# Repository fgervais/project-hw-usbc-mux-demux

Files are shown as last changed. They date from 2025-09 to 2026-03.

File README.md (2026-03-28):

# USB-C mux/demux

Overview

## Use-cases

Basically used to mux or demux usb 2.0 data bus with USB-PD up to and including
revision 3.1 at 48V.

Here's an illustration highlighting a couple use-cases:

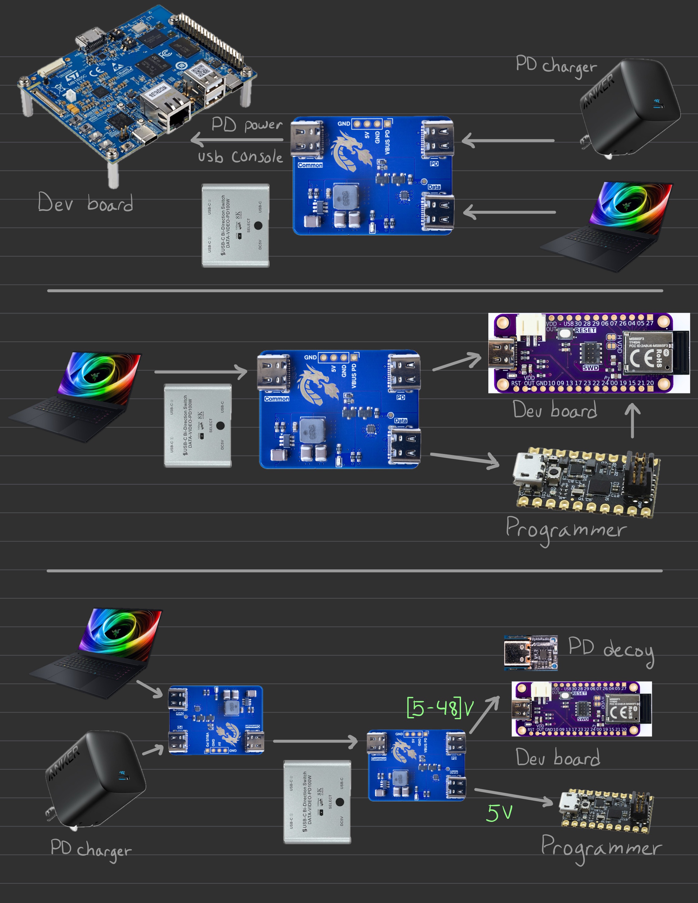
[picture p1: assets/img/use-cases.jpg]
Use-Cases


## Switching converter analysis

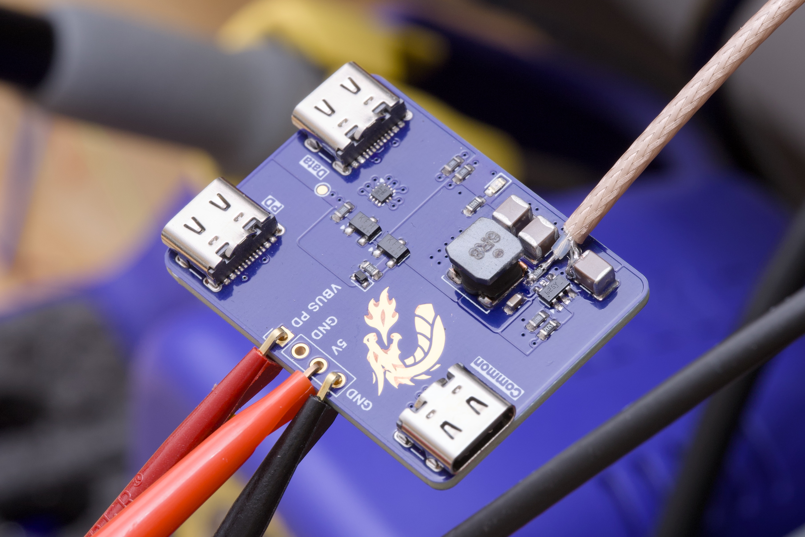
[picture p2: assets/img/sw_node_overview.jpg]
Overview


50 ohms series termination at the SW node.

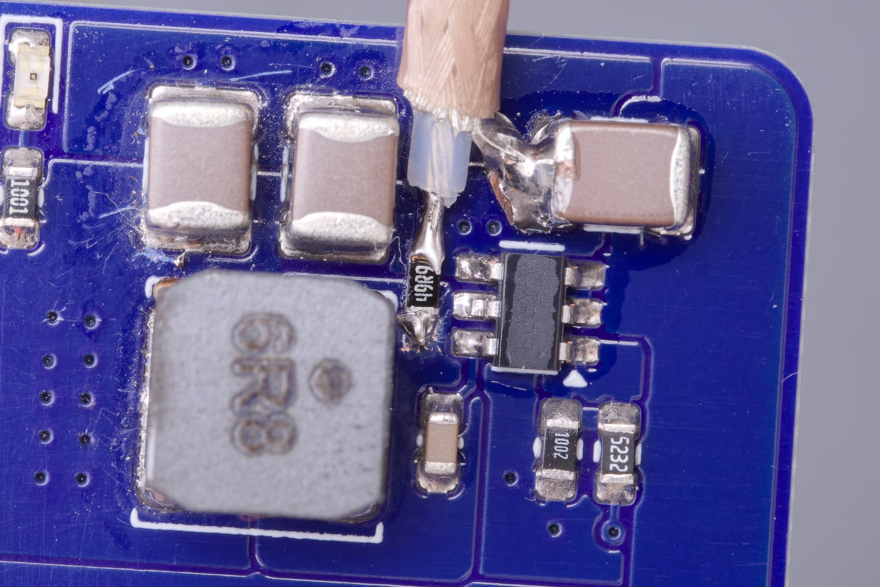
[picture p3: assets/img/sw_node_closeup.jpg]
Closeup


### Switch node

| Input Voltage | Waveform | Rising edge |
|---|---|---|
| 10V | Waveform | Rising |
| 20V | Waveform | Rising |
| 48V | Waveform | Rising |

### Output (5V)

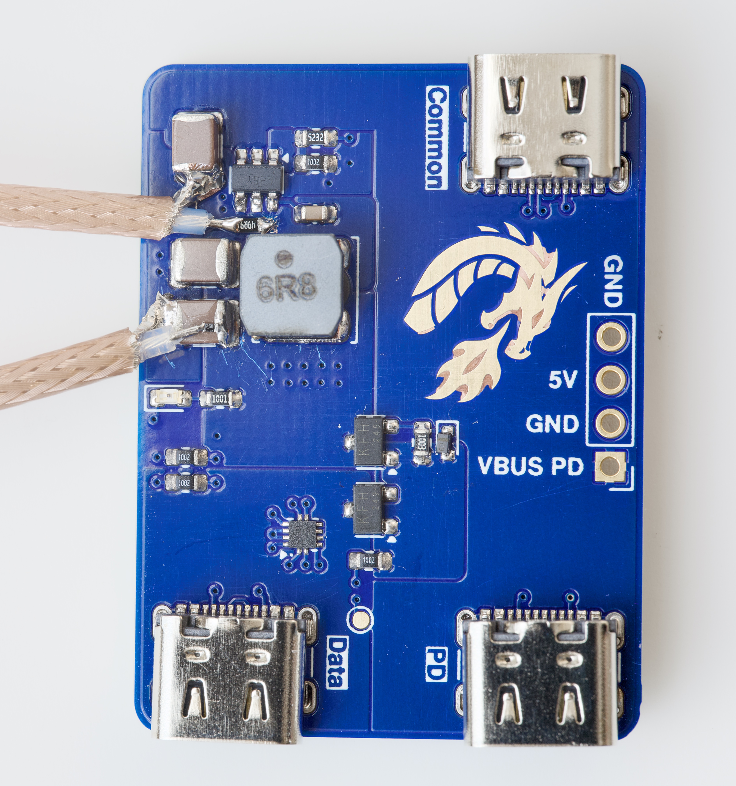
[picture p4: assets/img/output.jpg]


| Input Voltage | No Load | 50 mA | 500 mA | 1 A |
|---|---|---|---|-----|
| 10V | Waveform | Waveform | Waveform | Waveform |
| 20V | Waveform | Waveform | Waveform | Waveform |
| 48V | Waveform | Waveform | Waveform | Waveform |

| Input Voltage | No Load | 50 mA | 500 mA | 1 A |
|---|---|---|---|-----|
| 10V | Waveform | Waveform | Waveform | Waveform |
| 20V | Waveform | Waveform | Waveform | Waveform |
| 48V | Waveform | Waveform | Waveform | Waveform |

### Noise

| Input Voltage | No Load | 50 mA | 500 mA | 1 A |
|---|---|---|---|-----|
| 10V | 17.60 mV (0.35%) | 19.80 mV (0.40%) | 13.00 mV (0.26%) | 12.40 mV (0.25%) |
| 20V | 13.40 mV (0.27%) | 14.80 mV (0.30%) | 15.20 mV (0.30%) | 15.40 mV (0.31%) |
| 48V | 15.00 mV (0.30%) | 17.60 mV (0.35%) | 28.20 mV (0.56%) | 19.60 mV (0.39%) |

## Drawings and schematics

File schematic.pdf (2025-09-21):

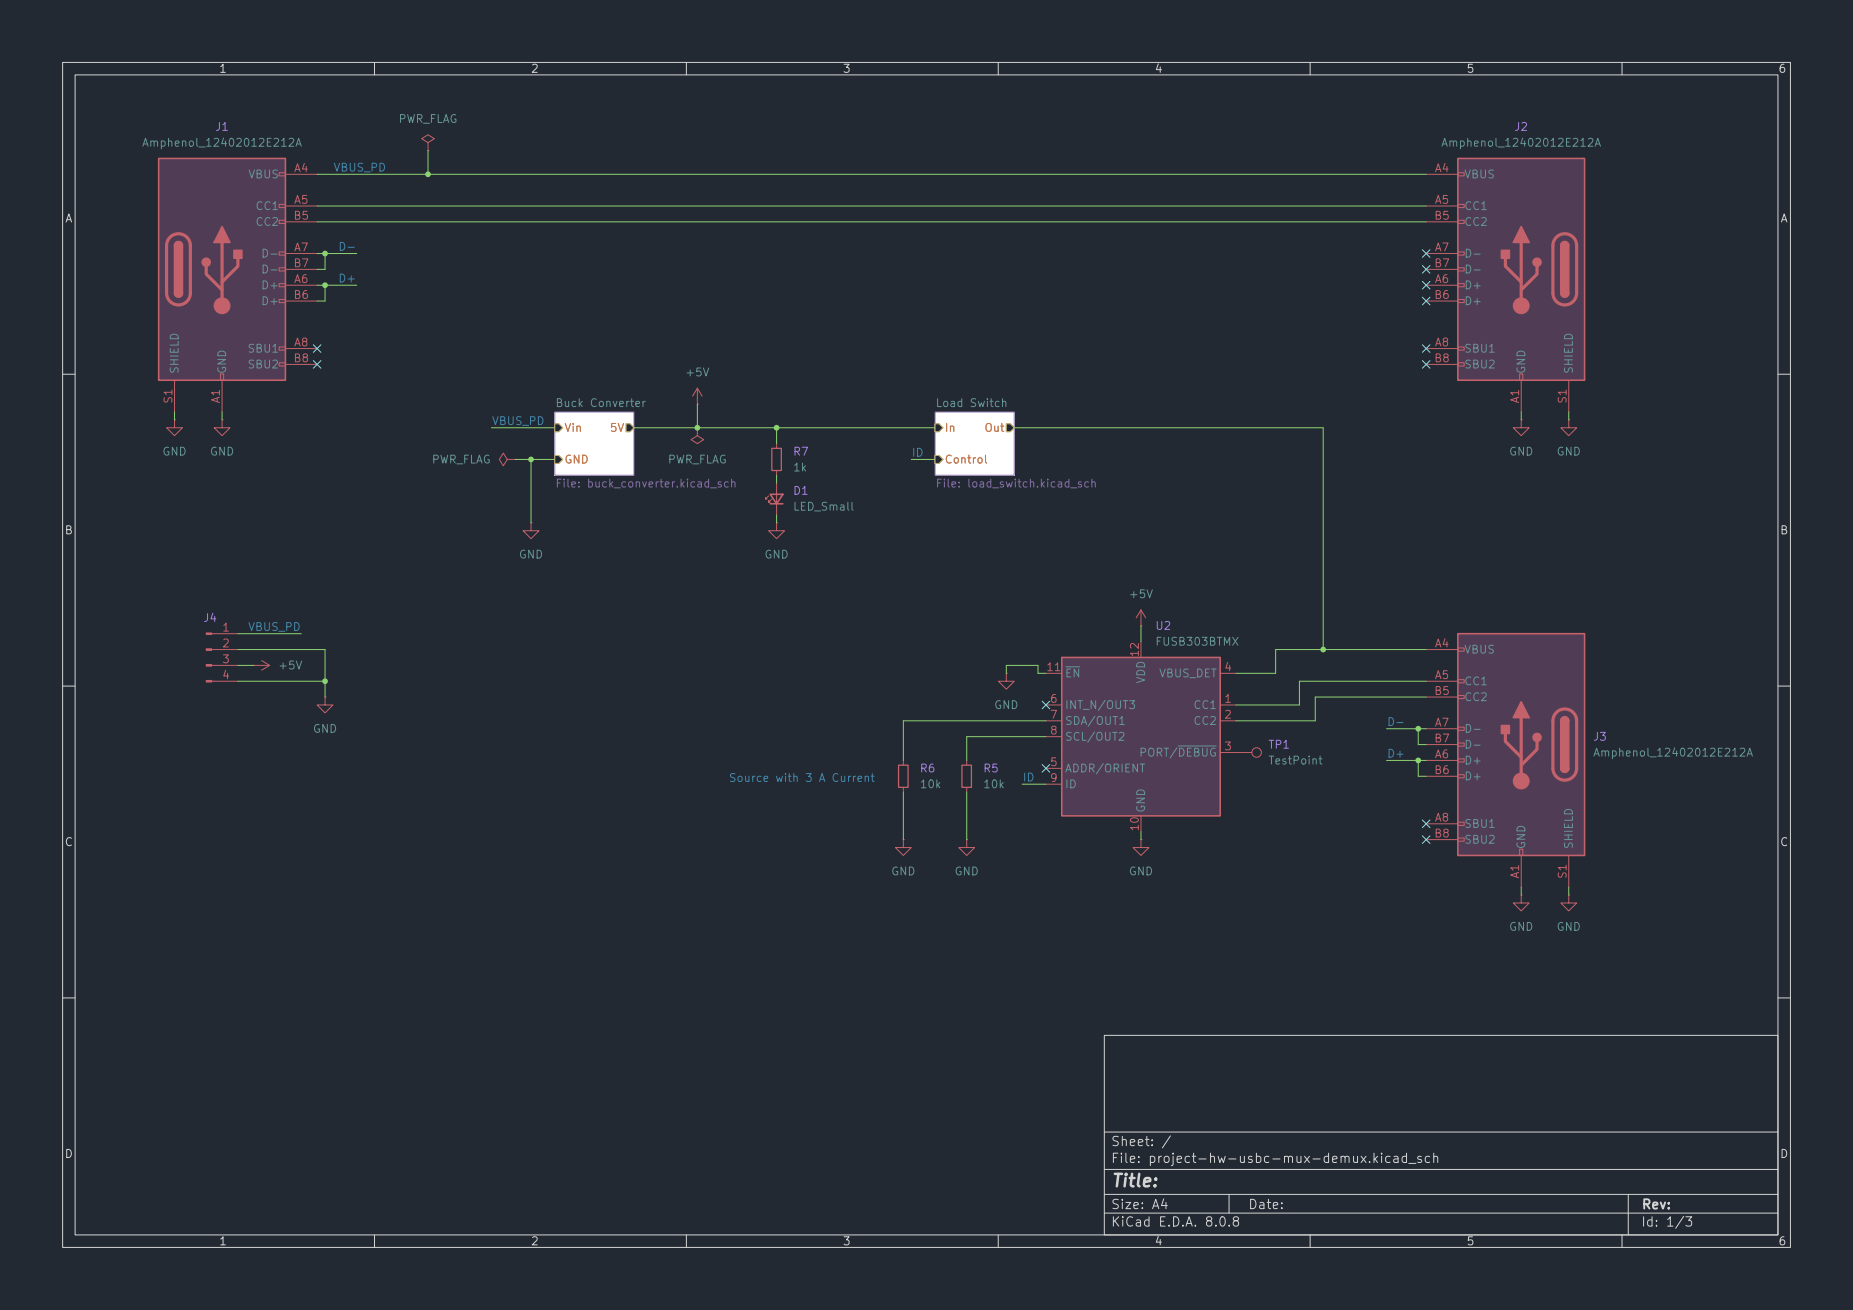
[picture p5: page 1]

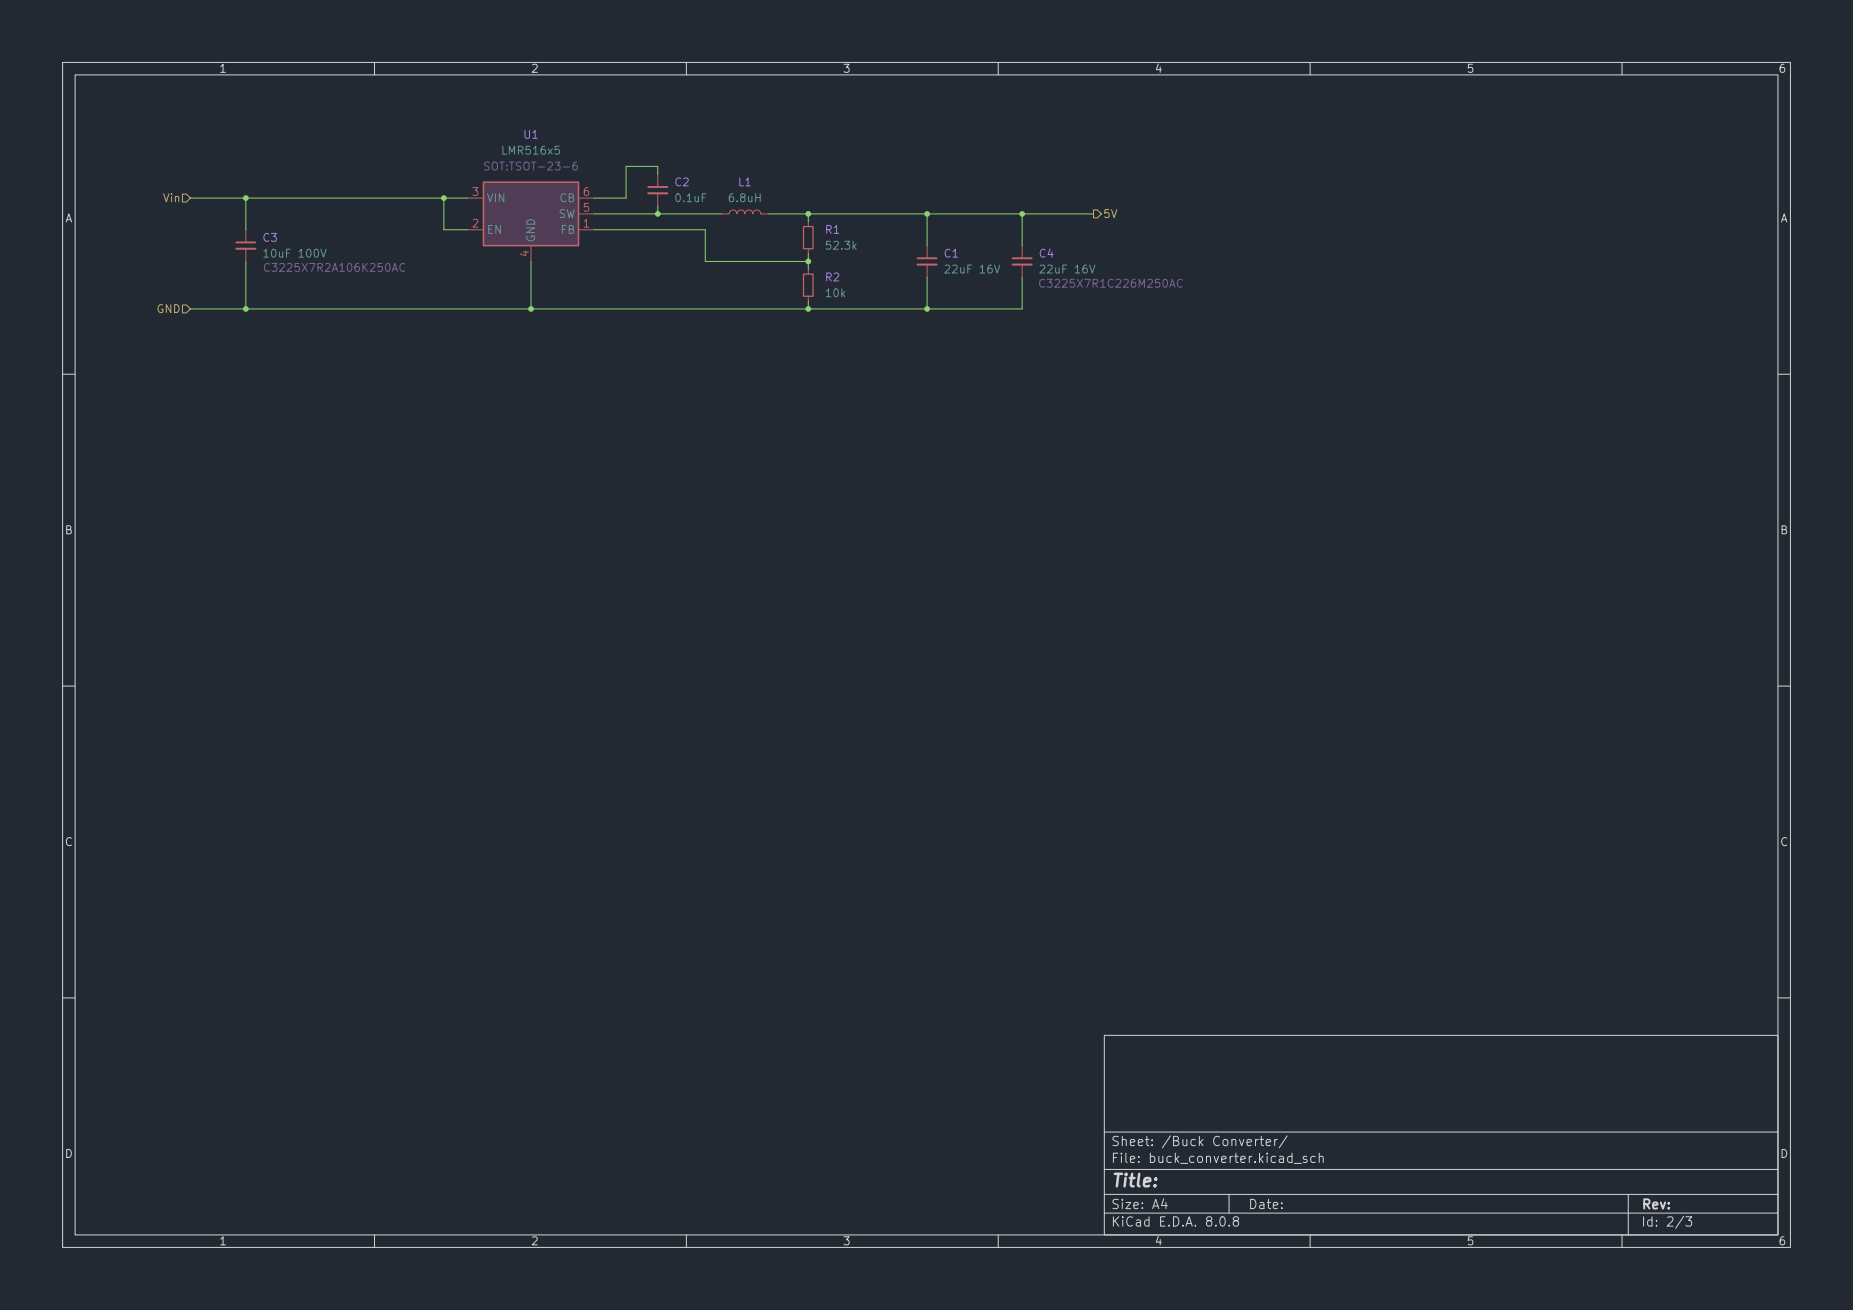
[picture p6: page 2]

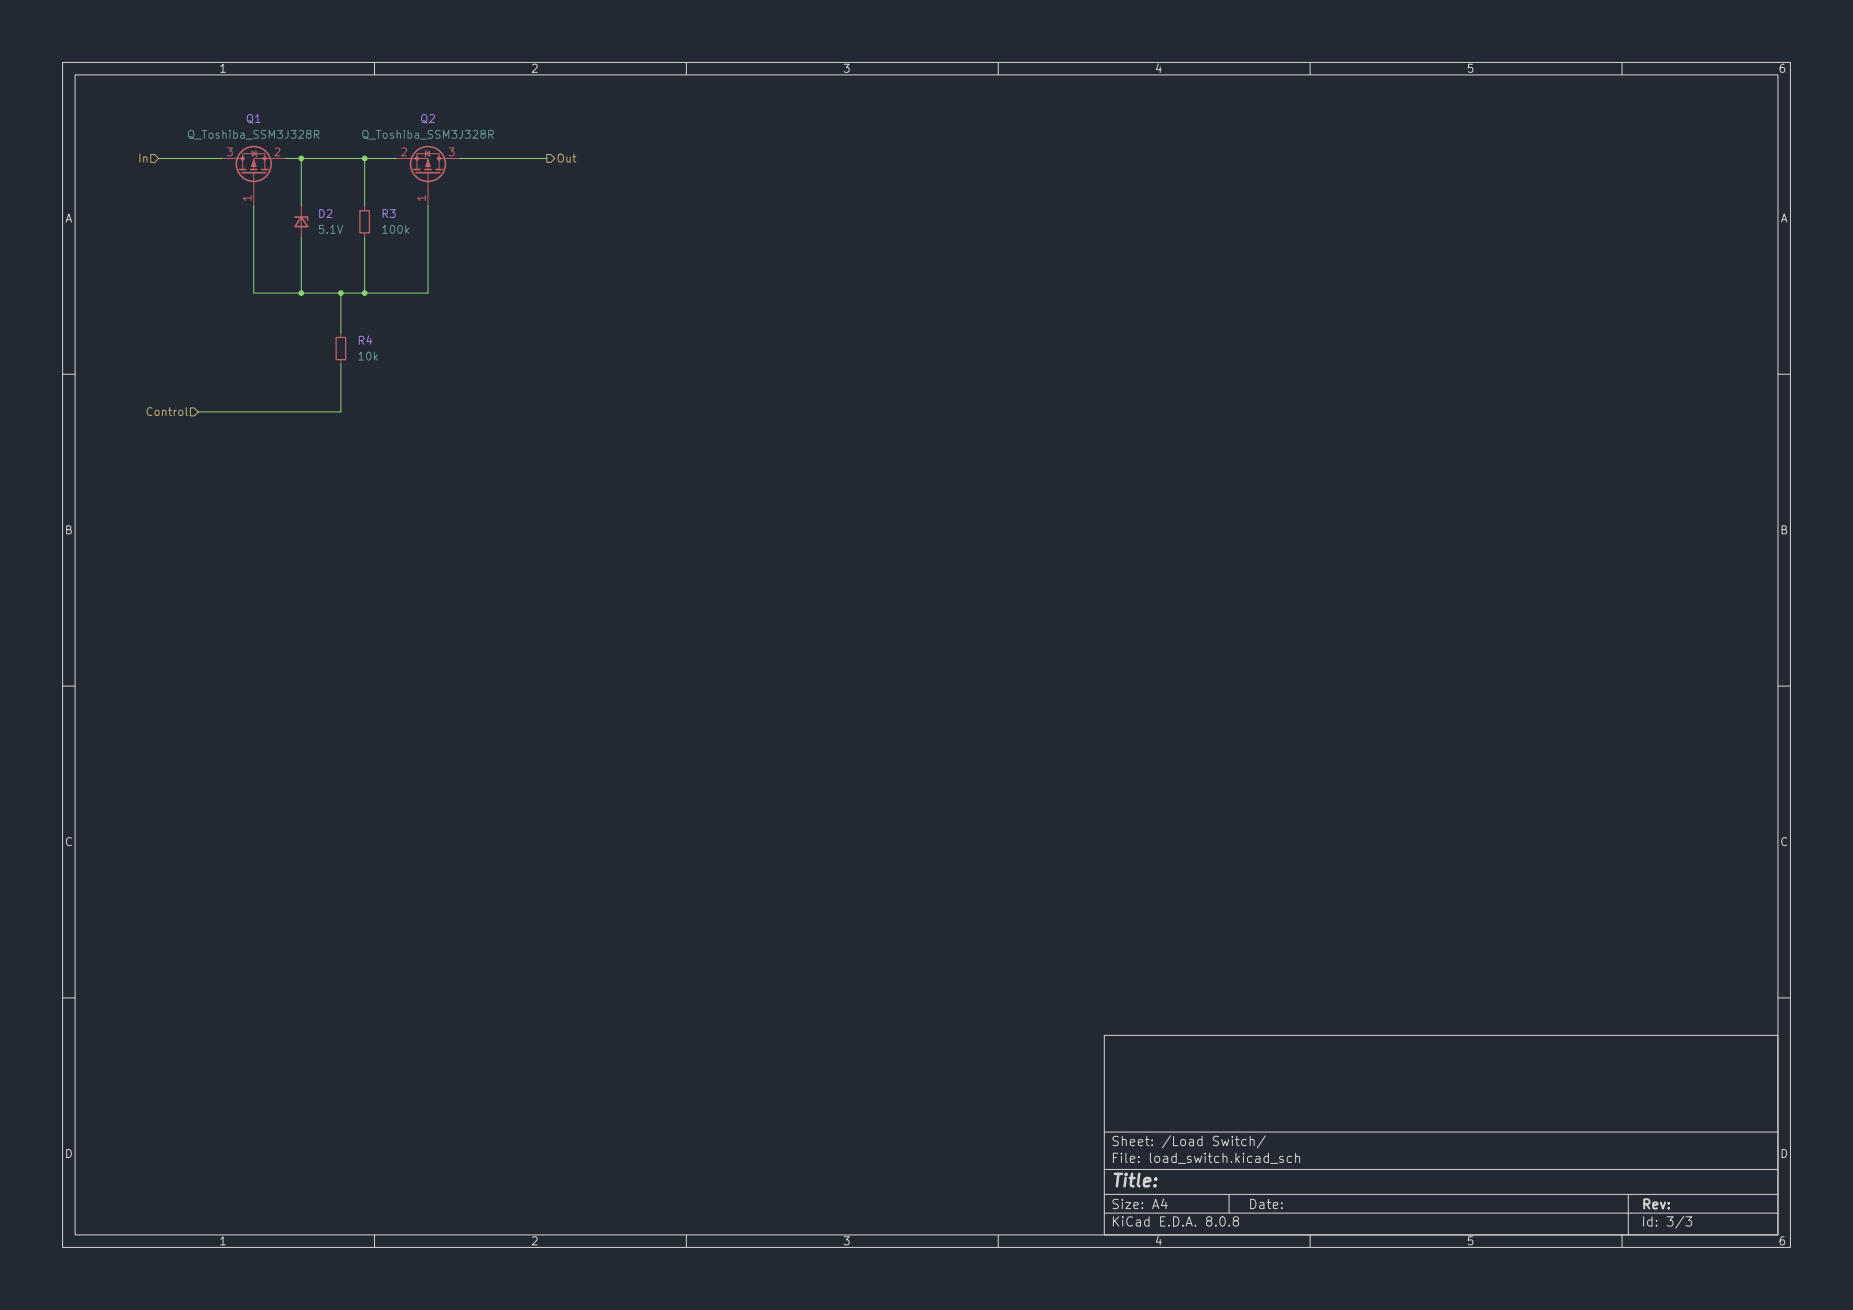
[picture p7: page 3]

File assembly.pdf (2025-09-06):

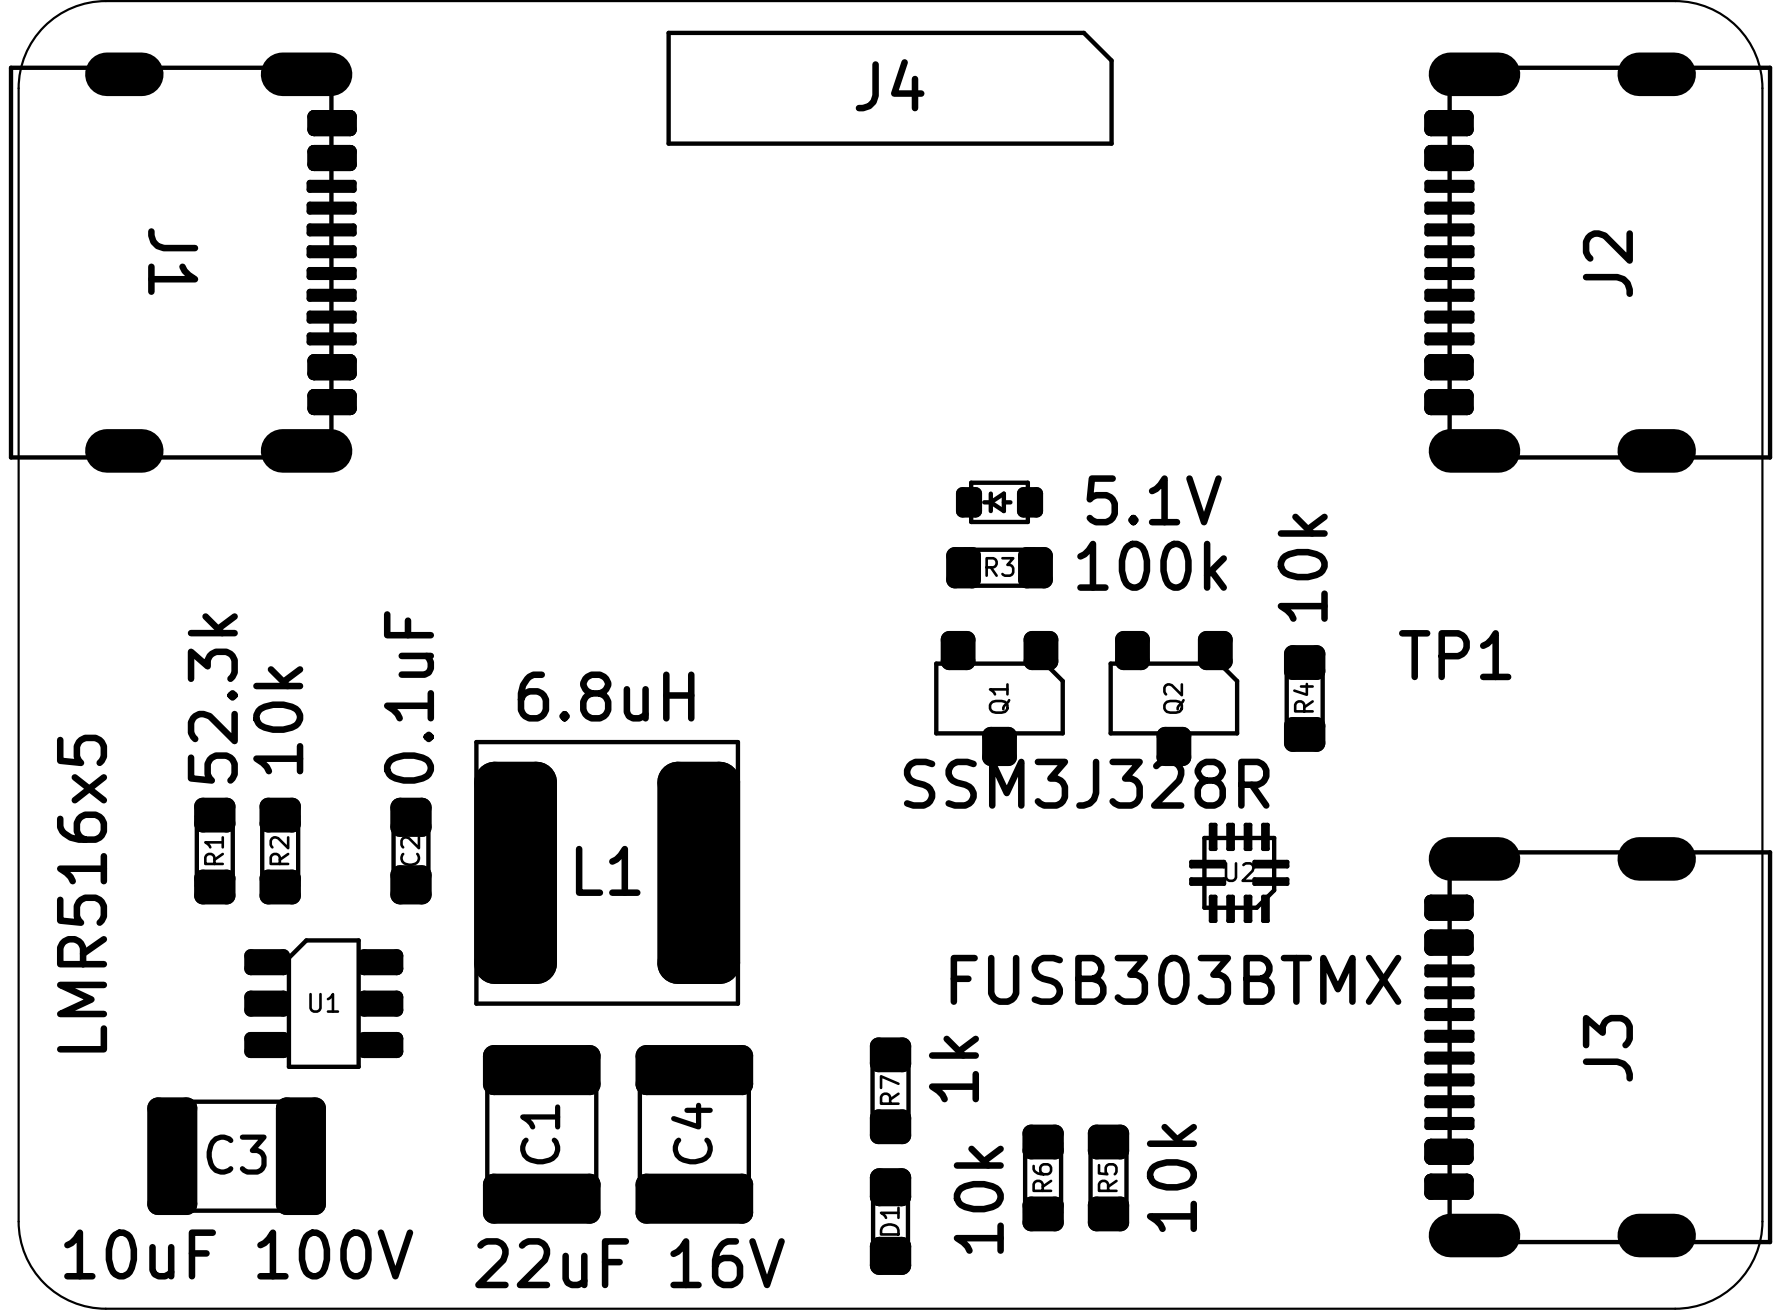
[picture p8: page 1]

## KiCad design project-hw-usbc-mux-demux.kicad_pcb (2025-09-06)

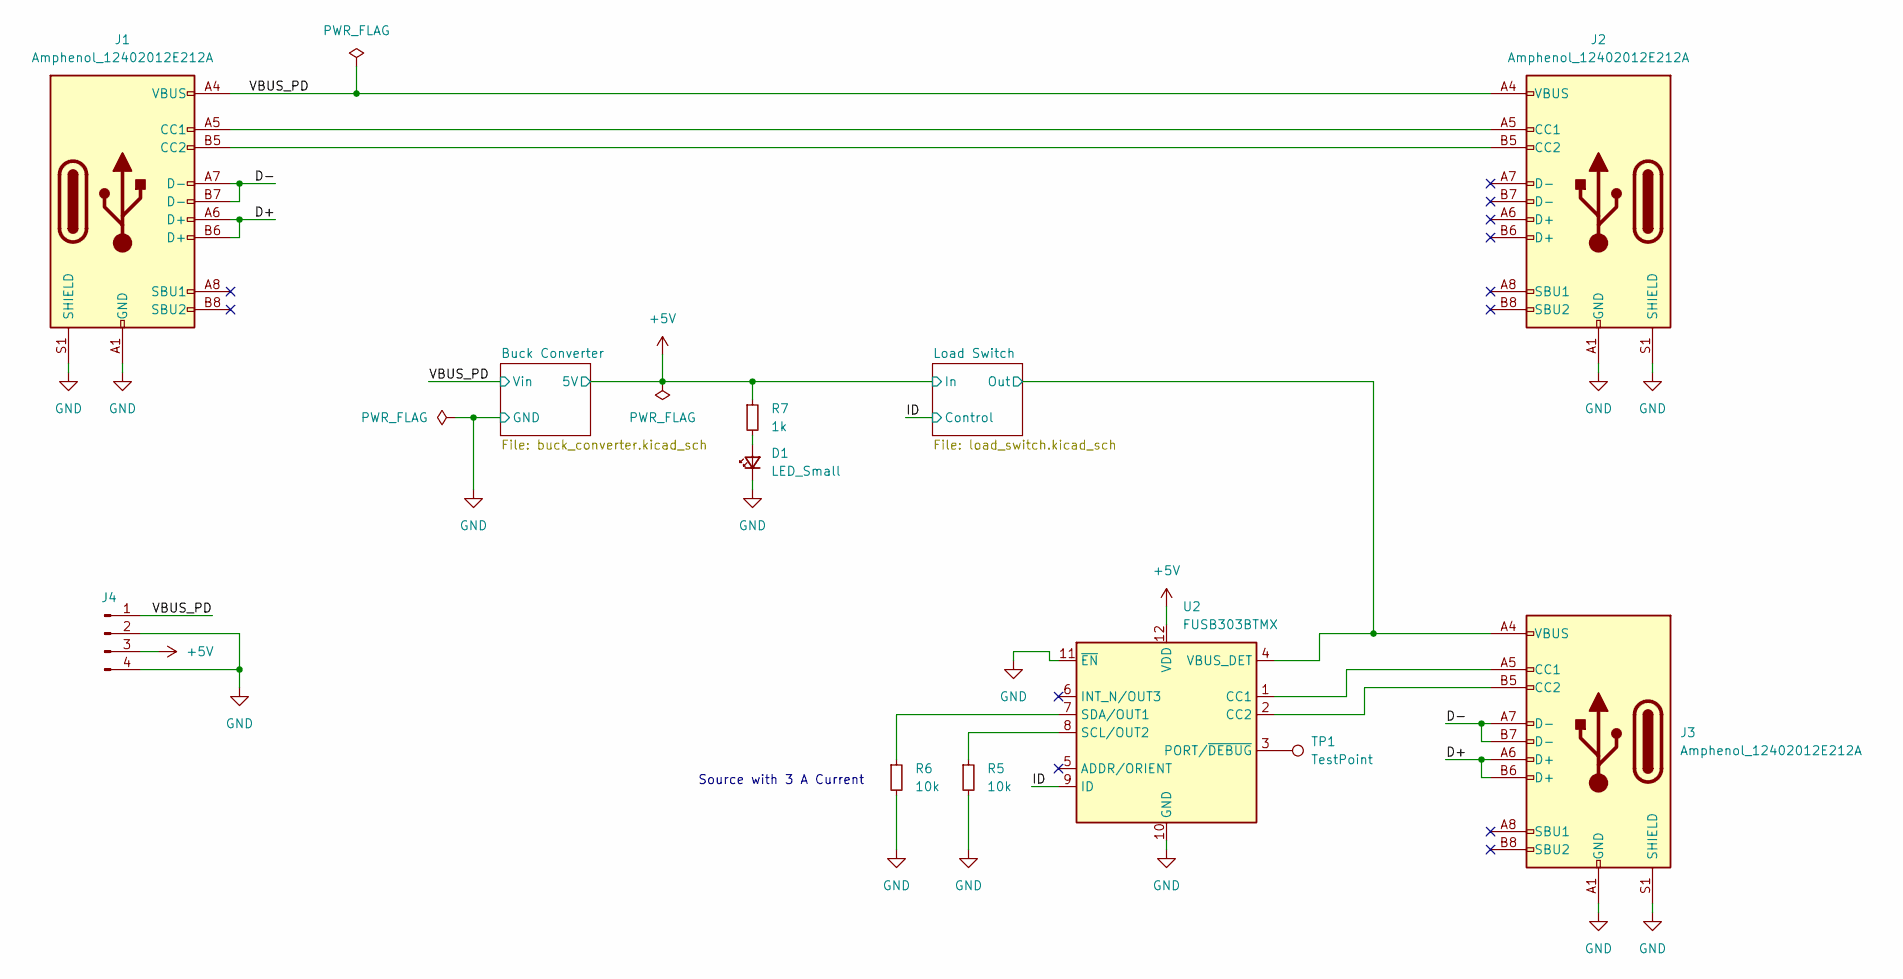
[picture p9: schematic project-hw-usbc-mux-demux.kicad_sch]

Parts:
D1: LED_Small; LED_0603_1608Metric
J1, J2, J3: Amphenol_12402012E212A
J4: Conn_01x04_Pin; PinHeader_1x04_P2.54mm_Vertical
R5, R6: 10k; R_0603_1608Metric
R7: 1k; R_0603_1608Metric
TP1: TestPoint; TestPoint_Pad_D1.0mm
U2: FUSB303BTMX; Texas_X2QFN-12_1.6x1.6mm_P0.4mm

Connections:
+5V: J4.3, R7.1, U2.12 (VDD); also elsewhere on the board
/D+: J1.A6 (D+), J1.B6 (D+), J3.A6 (D+), J3.B6 (D+)
/D-: J1.A7 (D-), J1.B7 (D-), J3.A7 (D-), J3.B7 (D-)
/ID: U2.9 (ID); also elsewhere on the board
/Load Switch/Out: J3.A4 (VBUS), J3.A9 (VBUS), J3.B4 (VBUS), J3.B9 (VBUS), U2.4 (VBUS_DET); also elsewhere on the board
/VBUS_PD: J1.A4 (VBUS), J1.A9 (VBUS), J1.B4 (VBUS), J1.B9 (VBUS), J2.A4 (VBUS), J2.A9 (VBUS), J2.B4 (VBUS), J2.B9 (VBUS), J4.1; also elsewhere on the board
GND: D1.1 (K), J1.A1 (GND), J1.A12 (GND), J1.B1 (GND), J1.B12 (GND), J1.S1 (SHIELD), J2.A1 (GND), J2.A12 (GND), J2.B1 (GND), J2.B12 (GND), J2.S1 (SHIELD), J3.A1 (GND), J3.A12 (GND), J3.B1 (GND), J3.B12 (GND), J3.S1 (SHIELD), J4.2, J4.4, R5.2, R6.2, U2.10 (GND), U2.11 (~EN); also elsewhere on the board
unnamed: D1.2 (A), R7.2
unnamed: J1.A5 (CC1), J2.A5 (CC1)
unnamed: J1.B5 (CC2), J2.B5 (CC2)
unnamed: J3.A5 (CC1), U2.1 (CC1)
unnamed: J3.B5 (CC2), U2.2 (CC2)
unnamed: TP1.1, U2.3 (PORT/~DEBUG)
unnamed: R5.1, U2.8 (SCL/OUT2)
unnamed: R6.1, U2.7 (SDA/OUT1)

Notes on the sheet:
Source with 3 A Current

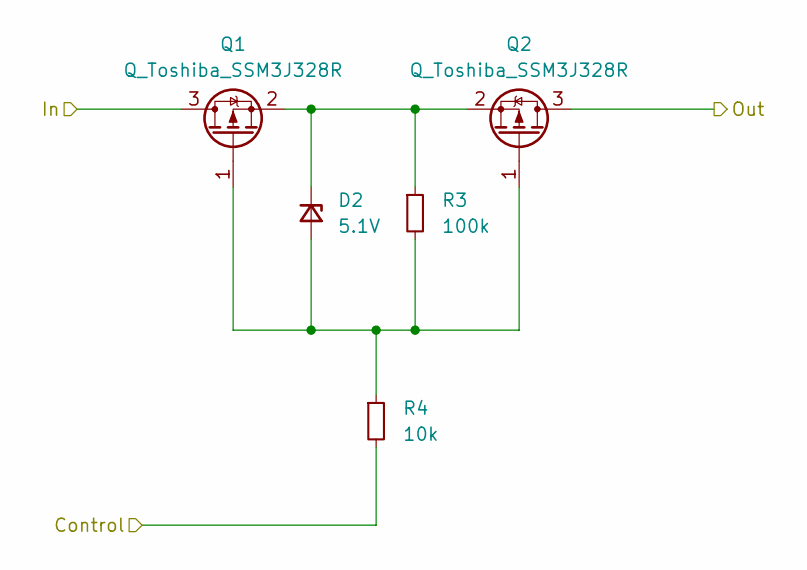
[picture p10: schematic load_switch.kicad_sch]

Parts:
D2: 5.1V; D_SOD-523
Q1, Q2: Q_Toshiba_SSM3J328R; SOT-23F
R3: 100k; R_0603_1608Metric
R4: 10k; R_0603_1608Metric

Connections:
+5V: Q1.3 (D); also elsewhere on the board
/ID: R4.2; also elsewhere on the board
/Load Switch/Out: Q2.3 (D); also elsewhere on the board
unnamed: D2.2 (A), Q1.1 (G), Q2.1 (G), R3.2, R4.1
unnamed: D2.1 (K), Q1.2 (S), Q2.2 (S), R3.1

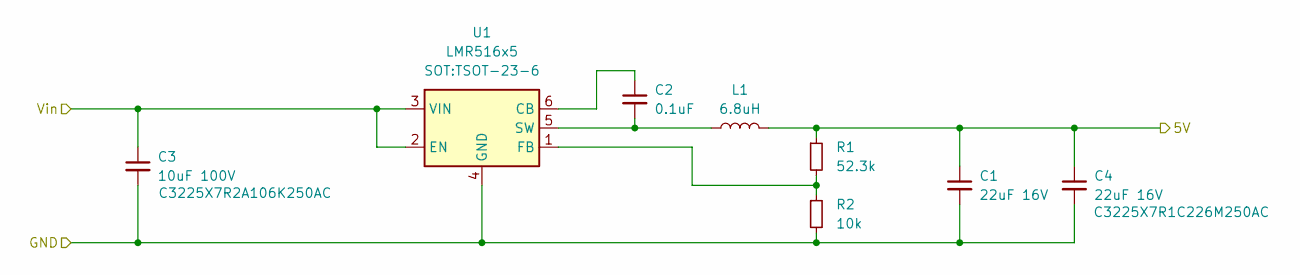
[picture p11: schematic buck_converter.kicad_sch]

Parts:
C1, C4: 22uF 16V; C_1210_3225Metric
C2: 0.1uF; C_0603_1608Metric
C3: 10uF 100V; C_1210_3225Metric
L1: 6.8uH; L_TDK_VLS6045EX_VLS6045AF
R1: 52.3k; R_0603_1608Metric
R2: 10k; R_0603_1608Metric
U1: LMR516x5; TSOT-23-6

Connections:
+5V: C1.1, C4.1, L1.2, R1.1; also elsewhere on the board
/VBUS_PD: C3.1, U1.2 (EN), U1.3 (VIN); also elsewhere on the board
GND: C1.2, C3.2, C4.2, R2.2, U1.4 (GND); also elsewhere on the board
unnamed: C2.1, U1.6 (CB)
unnamed: R1.2, R2.1, U1.1 (FB)
unnamed: C2.2, L1.1, U1.5 (SW)

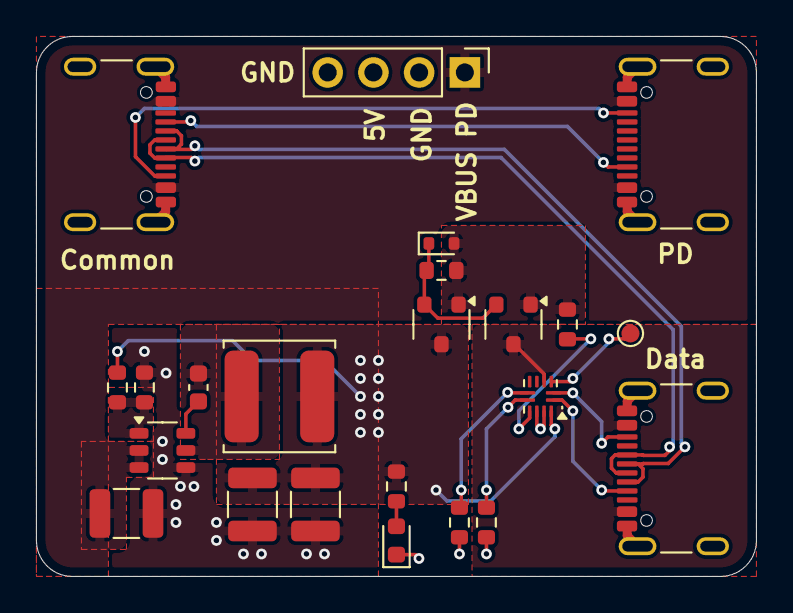
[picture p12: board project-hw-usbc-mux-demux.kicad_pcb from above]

Board: 4 copper layers, 40.0 x 30.0 mm, 23 parts (0 on the bottom side), 20 nets.

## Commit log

2025-08-16 Add black kicad project
    [project-hw-usbc-mux-demux.kicad_pcb, project-hw-usbc-mux-demux.kicad_sch]
2025-08-16 sch: add buck converter
    [buck_converter.kicad_sch, project-hw-usbc-mux-demux.kicad_sch]
2025-08-17 sch: first draft
    [buck_converter.kicad_sch, load_switch.kicad_sch, project-hw-usbc-mux-demux.kicad_sch]
2025-08-20 sch: add zener diode
    [load_switch.kicad_sch, project-hw-usbc-mux-demux.kicad_sch]
2025-08-20 sch: fix errors
    [buck_converter.kicad_sch, project-hw-usbc-mux-demux.kicad_sch]
2025-08-20 sch: add test point
    [project-hw-usbc-mux-demux.kicad_sch]
2025-08-21 sch: add usb footprint
    [project-hw-usbc-mux-demux.kicad_sch]
2025-08-21 sch: add power connectors
    [project-hw-usbc-mux-demux.kicad_sch]
2025-08-21 pcb: route converter
    [project-hw-usbc-mux-demux.kicad_pcb]
2025-08-22 pcb: route most of the board
    [project-hw-usbc-mux-demux.kicad_pcb, project-hw-usbc-mux-demux.kicad_sch]
2025-08-22 pcb: first draft ready
    [project-hw-usbc-mux-demux.kicad_pcb]
2025-08-22 pcb: add silkscreen
    [project-hw-usbc-mux-demux.kicad_pcb]
2025-08-22 pcb: make pd poor wider
    [project-hw-usbc-mux-demux.kicad_pcb]
2025-08-22 pcb: add version
    [project-hw-usbc-mux-demux.kicad_pcb]
2025-08-22 pcb: add dragon logo
    [project-hw-usbc-mux-demux.kicad_pcb]
2025-08-23 pcb: hide header 3d model
    [project-hw-usbc-mux-demux.kicad_pcb]
2025-08-23 Add gerber files
    [project-hw-usbc-mux-demux-B_Cu.gbr, project-hw-usbc-mux-demux-B_Mask.gbr, project-hw-usbc-mux-demux-B_Paste.gbr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]
2025-09-06 Add assembly file
    [project-hw-usbc-mux-demux.kicad_pcb]
2025-09-21 Add schematic file
2026-02-07 Add regulator analysis to README
